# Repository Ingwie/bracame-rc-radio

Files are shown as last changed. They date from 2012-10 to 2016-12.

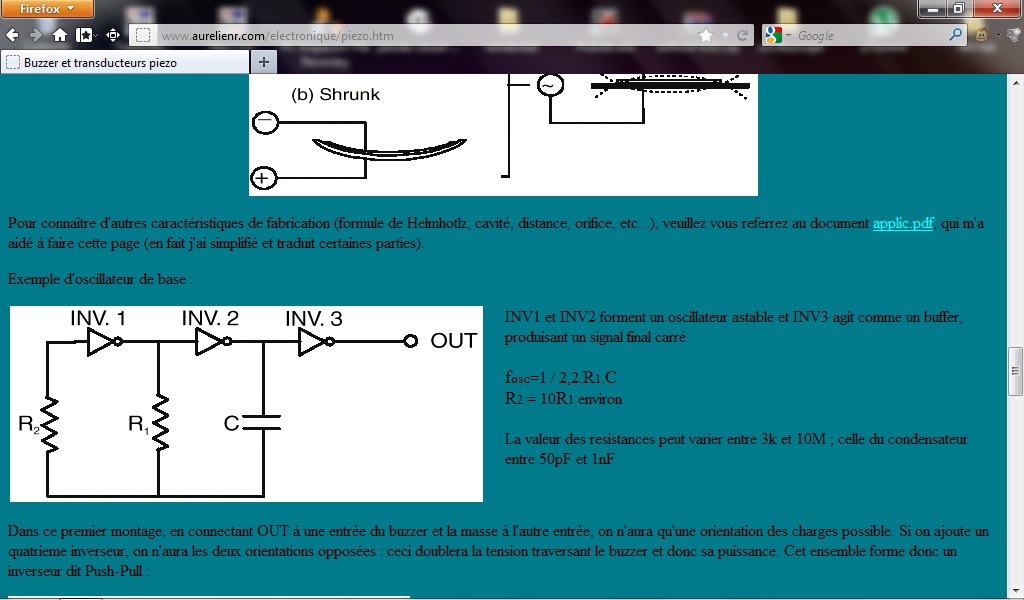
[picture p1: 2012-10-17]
wiki/oscilbuzzer.jpg

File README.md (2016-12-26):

# bracame-rc-radio
Automatically exported from code.google.com/p/bracame-rc-radio

Une radio RC pour avions maison à base de µ contrôleur STM8S. DIY RC TX.

Afficheur 2 X 16.

Émetteur au choix (compatible PPM)

8 voies en entrées et sorties :

8 sorties PPM (j'utilise le module DIY corona ...)

8 entrées : 6 proportionnelles : 2 manches + 2 potards (voir photo) 2 switchs 3 positions.

Expo, dualrate, min neutre max sur chaque voies. Consommation batterie moteur (simulée) 18 mixeurs : entrée, sortie, gain +, gain - et 5 courbes de 6 points par cadrant.

Et plein d'autres choses ..... 

Après plusieurs années de bons et loyaux services, abandon au profit d'openAVRc

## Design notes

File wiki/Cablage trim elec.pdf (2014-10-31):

Utilisation | Pin | LQFP pin# | Partagé Avec | Discovery/ pin#
| PA0 | N/A | N/A | N/A | 1 | 2 | 3 | 4 | 5 | 6 | 7 | 8 | 9
Quartz | PA1 | 2 | OscIn | CN1-2 | + | - | ppm+ | ppm- | trimdyn | tor1+ | tor1- | tor2+ | tor2-
Quartz | PA2 | 3 | OscOut | CN1-3
Entrée TOR1+ | PA3 | 9 | TIM3_CH1 / TIM2_CH3 | CN1-9
Entrée TOR1- | PA4 | 10 | Exclusive | CN1-10
Entrée TOR2+ | PA5 | 11 | Exclusive | CN1-11
Entrée TOR2- | PA6 | 12 | Exclusive | CN1-12
| PA7 | N/A | N/A | N/A
Entrée manche 1 | PB0 | 22 | TIM1_CH1N / AIN0 | CN3-10
Entrée manche 2 | PB1 | 21 | TIM1_CH2N / AIN1 | CN3-9
Entrée manche 3 | PB2 | 20 | TIM1_CH3N / AIN2 | CN3-8
Entrée manche 4 | PB3 | 19 | TIM1_ETR / AIN3 | CN3-7
Entrée potar 1 | PB4 | 18 | I2C_SCL / AIN4 | CN3-6
Entrée potar 2 | PB5 | 17 | I2C_SDA / AIN5 | CN3-5
Mesure batterie | PB6 | 16 | AIN6 | CN3-4
Phase | PB7 | 15 | AIN7 | CN3-3
| PC0 | N/A | N/A | N/A
Touche BAS | PC1 | 26 | TIM1_CH1 / UART2_CK | CN2-2
LCD Register Select | PC2 | 27 | TIM1_CH2 | CN2-3
LCD Enable | PC3 | 28 | TIM1_CH3 | CN2-4
LCD Bus 1 | PC4 | 29 | TIM1_CH4 | CN2-5
LCD Bus 2 | PC5 | 30 | SPI_SCK | CN2-6
LCD Bus 3 | PC6 | 33 | SPI_MOSI | CN3-9
LCD Bus 4 | PC7 | 34 | SPI_MISO | CN3-10
Sortie Led discovery/trim + | PD0 | 41 TIM3_CH2 / TIM1_BKIN / CLK_CCO | | CN4-5
SWIM | PD1 | 42 | SWIM | CN4-6
Sortie Trim - | PD2 | 43 | TIM3_CH1 / TIM2_CH3 | CN4-7
Sortie PPM | PD3 | 44 | TIM2_CH2 / ADC_ETR | CN4-8
Bip (buzzer) | PD4 | 45 | TIM2_CH1 / BEEP | CN4-9
Entrée Trim manche 1 | PD5 | 46 | UART2_TX | CN4-10
Entrée Trim manche 0 | PD6 | 47 | UART2_RX | CN4-11
Entrée Trim Dynamique | PD7 | 48 | TLI / TIM1_CH4 | CN4-12
Sécu Mot. | PE0 | 40 | CLK_CCO | CN4-4
I2C SCL (24C256) | PE1 | 39 | I2C_SCL | CN4-3
I2C SDA (24C256) | PE2 | 38 | I2C_SDA | CN4-2
Expo + DualRate | PE3 | 37 | TIM1_BKIN | CN4-1
| PE4 | N/A | N/A | N/A
Touche Droite | PE5 | 25 | SPI_NSS | CN2-1
Entrée Trim manche 3 | PE6 | 24 | AIN9 | CN3-12
Entrée Trim manche 2 | PE7 | 23 | AIN8 | CN3-11
Touche Gauche | PG0 | 35 | Exclusive | CN2-11
Touche Haut | PG1 | 36 | Exclusive | CN2-12

DB9

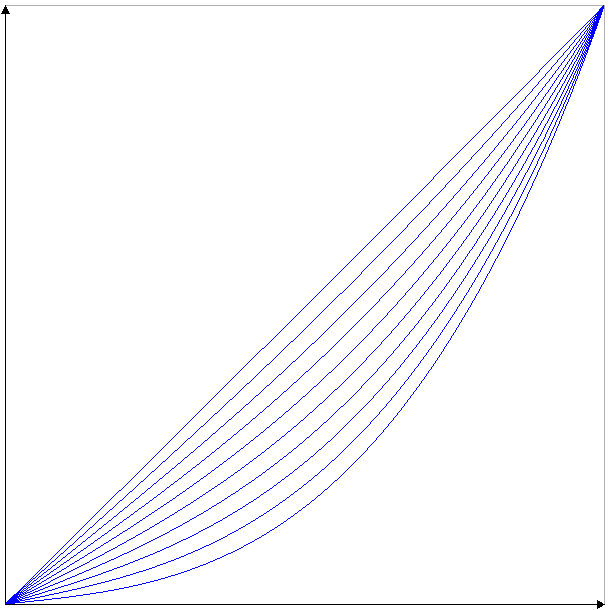
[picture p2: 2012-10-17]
wiki/expo.png

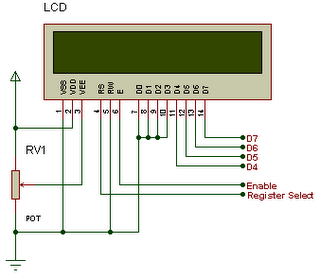
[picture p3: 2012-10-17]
wiki/lcd.png

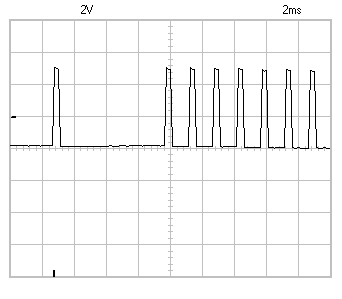
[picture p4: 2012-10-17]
wiki/ppm.bmp

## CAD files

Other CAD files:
branches/tx/src/rc-tx.stp

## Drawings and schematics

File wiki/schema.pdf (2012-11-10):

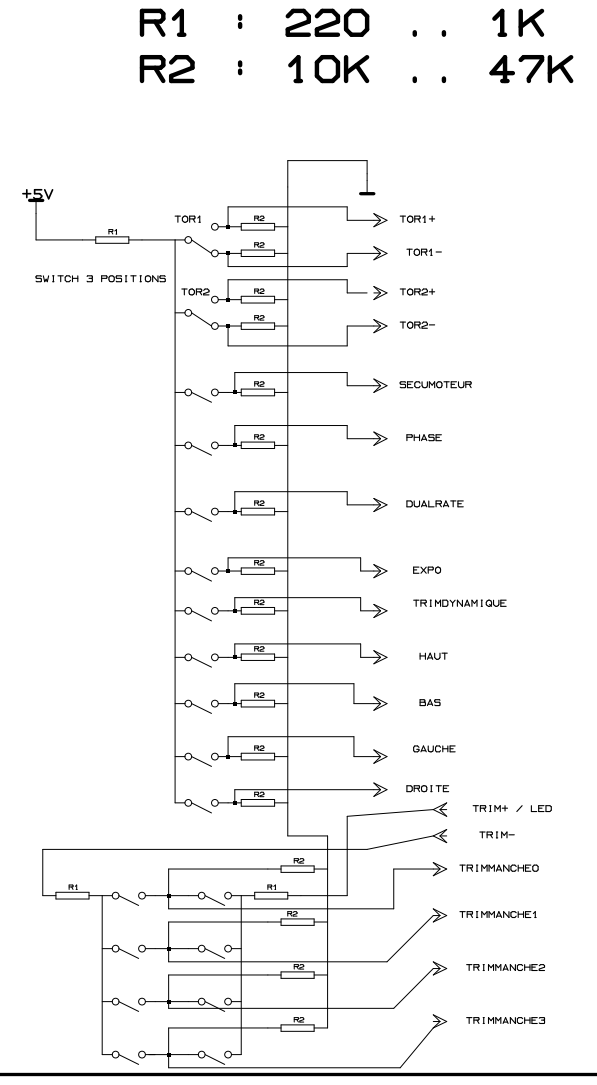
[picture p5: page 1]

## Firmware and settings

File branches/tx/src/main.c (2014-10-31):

/* Bracame RC TX */
/* */
/* Ajout de trims electroniques pour fonctionnement avec nouveaux manches (hitec aurora 9)*/
/* */
/* Ajout dans utilitaire : visualisation des entrées sorties et potars */
/* */
/* Ajout de la gestion du retour au neutre pour trimdyn */
/* */
/* Un seul etalonnage des manches pour tous les modeles : 5 possibles maintenant (petite modif), ajout réglage tempo du menu*/
/* */
/* Multiplexage des switchs secumoteur, phase, expo et dr liberation des entrées i2c pour ise en place d'une 24C256*/
/* */
/* Ecriture de routines perso i2c : le stm8 rev Y est buggé sur l'i2c. 24C256 fonctionnelle*/
/* (15 modèles 3 phases et 18 mixeurs maintenant. Reste a ajouter un switch 3 positions pour les phases*/
/* */
/* Amelioration de secumoteur */
/* */
/* Switch 3 positions Phase en place, cable sur PB7 (reste donc une place avec secumoteur */
/* */
/* */


#include "stm8s.h"
#include "tx.h"
#include "delay.h"
#include "hd44780.h"
#include "menu.h"
#include "iic.h"

extern _Bool Menu_on;
extern _Bool sec;
extern _Bool Menu_actif;
extern _Bool popup;
extern _Bool Menu_raz;
extern _Bool synchro;
extern u8 Tempo_menu;
extern u8 jeton;
extern u8 channel;

u8 modele_actuel;
u8 phase_actuelle = 0;
u8 phase_a_charger = 0;
_Bool phase_change = 0;
_Bool phase_changemenu = 0;
u8 nom_modele[12] = "           \n";



_Bool trimdyn = 0; // Lié a PD7
_Bool switchdr = 0; // PE2
_Bool expon = 0; // PE3
_Bool secumot = 1; // PE0
_Bool tor1plus = 0; // PA3
_Bool tor1moins = 0; // PA4
_Bool tor2plus = 0; // PA5
_Bool tor2moins = 0; // PA6
_Bool gazazero = 0; // Detection manche des gaz au mini pour fonction secumoteur

struct_input NEAR input;
struct_output NEAR output;
struct_param_phase NEAR param_phase[NUM_PHASE];
u16 trimmem[NUM_OUTPUT];


volatile _Bool flashencour = 0;
_Bool menudyn = 0;
_Bool switchinfo = 0;
_Bool haut = 0; // PG1
_Bool bas = 0; // PC1
_Bool gauche = 0; // PG0
_Bool droite = 0; // PE5

_Bool trim0plus = 0;
_Bool trim0moins = 0;
_Bool trim1plus = 0;
_Bool trim1moins = 0;
_Bool trim2plus = 0;
_Bool trim2moins = 0;
_Bool trim3plus = 0;
_Bool trim3moins = 0;
_Bool trimflag = 0;
_Bool trimchange = 0;
u8 trimstep = 2;

u16 temps_calcul_trame;
u8 secondesurcinq;
u8 secondes;
u8 minutes;
u16 chargeeaccus = 9999;

u8 ratiotrimdyn = 1;
u8 tempotrimdyn = 0;
u8 temptrimdyn = 20;
u8 tempsmenu = 10;
_Bool trimdynencour = 0;
_Bool manche0neutre = 0;
_Bool manche1neutre = 0;
_Bool manche2neutre = 0;
_Bool manche3neutre = 0;
_Bool trimdynmanche0 = 0;
_Bool trimdynmanche1 = 0;
_Bool trimdynmanche2 = 0;
_Bool trimdynmanche3 = 0;

u8 tempsbip1 = 0;
u8 tempsbip2 = 0;
u8 tempsbip3 = 0;
u8 tempsbip4 = 0;
u8 tempsbip5 = 0;
_Bool bipon = 1;


/////////////////////////////////////////////////////////////////////////////

/*void duree(void) // pour debugger optimiser
{
		static u16 debut;
		static u16 fin;
		static u16 temps;
		debut =  TIM3_GetCounter();  


		// fonction a mesurer
		//lectureswitch();

		fin = TIM3_GetCounter();
		if (fin > debut)
		{
				temps =(fin - debut) * 32;
				LCD_printtruc(1,9,"%i\n",temps);
				LCD_printtruc(2,10,"%i\n",channel);
		}
}*/

void bip(u8 temps1,u8 temps2,u8 temps3,u8 temps4,u8 temps5) // temps x 0.2 sec
{
	if (bipon)
	{
		GPIO_WriteLow(GPIOD,GPIO_PIN_4);
		tempsbip1 = temps1 + 1;
		tempsbip2 = temps2 + tempsbip1;
		tempsbip3 = temps3 + tempsbip2;
		tempsbip4 = temps4 + tempsbip3;
		tempsbip5 = temps5 + tempsbip4;
	}
}

void lcd_charge_spcaracteres(void)
{
	const char cur[64] =
	{
		0x00, 0x00, 0x00, 0x00, 0x00, 0x00, 0x00, 0x1F,
		0x00, 0x00, 0x00, 0x00, 0x00, 0x00, 0x1F, 0x00,
		0x00, 0x00, 0x00, 0x00, 0x00, 0x1F, 0x00, 0x00,
		0x00, 0x00, 0x00, 0x00, 0x1F, 0x00, 0x00, 0x00,
		0x00, 0x00, 0x00, 0x1F, 0x00, 0x00, 0x00, 0x00,
		0x00, 0x00, 0x1F, 0x00, 0x00, 0x00, 0x00, 0x00,
		0x00, 0x1F, 0x00, 0x00, 0x00, 0x00, 0x00, 0x00,
		0x1F, 0x00, 0x00, 0x00, 0x00, 0x00, 0x00, 0x00
	};
	
	LCD_CMD(CGRAM_address_start);
	LCD_LOAD_CGRAM(cur,8);
}

void biponoff(void)
{
	LCD_DISP_OFF();
	LCD_CLEAR_DISPLAY();
	Menu_actif = 1;
	popup = 1;
	Tempo_menu = 8;

	bipon = !bipon;
	switchinfo = 1;
	if (bipon)
	{
		LCD_printtruc(1,6,"Bip On",0);
		bip(2,1,1,0,0);
	}
	else
	{
		LCD_printtruc(1,6,"Bip Off",0);
	}
	
	LCD_DISP_ON();
}

void razchrono(void)
{
	minutes = secondes = 0;
	chargeeaccus = 9999;
	bip(2,1,2,0,0);
}

u8 nivbar(u16 sortie) // Pour baragraphe info
{	
	sortie -= (MIN_COURSE - MIN_COURSE/8);
	sortie /= 166;
	return sortie;
}

void info(void) // Affichage pendant le vol ...
{
	u8 i;
	u16 volt;
	u8 barout;
	char lhaut[NUM_OUTPUT + 1];
	char lbas[NUM_OUTPUT + 1];
	const char esp = 32;
	
	for(i = 0; i < NUM_OUTPUT ; i++)
	{
		barout = nivbar(output.usValueOut[i]); //calcul pour affichage pendant le vol
		
		switch (barout)
		{
		case 0:
			lbas[i] = '\0';
			lhaut[i] = esp;
			break;
		case 1:
			lbas[i] = '\1';
			lhaut[i] = esp;
			break;
		case 2:
			lbas[i] = '\2';
			lhaut[i] = esp;
			break;
		case 3:
			lbas[i] = '\3';
			lhaut[i] = esp;
			break;
		case 4:
			lbas[i] = '\4';
			lhaut[i] = esp;
			break;
		case 5:
			lbas[i] = '\5';
			lhaut[i] = esp;
			break;
		case 6:
			lbas[i] = '\6';
			lhaut[i] = esp;
			break;
		case 7:
			lbas[i] = '\7';
			lhaut[i] = esp;
			break;
		case 8:
			lbas[i] = esp;
			lhaut[i] = '\0';
			break;
		case 9:
			lbas[i] = esp;
			lhaut[i] = '\1';
			break;
		case 10:
			lbas[i] = esp;
			lhaut[i] = '\2';
			break;
		case 11:
			lbas[i] = esp;
			lhaut[i] = '\3';
			break;
		case 12:
			lbas[i] = esp;
			lhaut[i] = '\4';
			break;
		case 13:
			lbas[i] = esp;
			lhaut[i] = '\5';
			break;
		case 14:
			lbas[i] = esp;
			lhaut[i] = '\6';
			break;
		case 15:
			lbas[i] = esp;
			lhaut[i] = '\7';
			break;
		}
	}
	
	lhaut[NUM_OUTPUT] = 10; // Caractere "/n"
	lbas[NUM_OUTPUT] = 10;
	LCD_LOCATE(1,1);
	LCD_printstring(lhaut);
	LCD_LOCATE(2,1);
	LCD_printstring(lbas);

	// Canal en cours d'emission
	LCD_printtruc(1,9,"%u\n",channel);

	// Temps restant aprés la boucle de calcul de la trame
	temps_calcul_trame = (LONGUEUR_TRAME - temps_calcul_trame);
	temps_calcul_trame /= 1000;
	barout = (u8)(temps_calcul_trame);
	// 1 = 0.5 mS
	if (barout < 1) barout = '!';
	else if (barout < 3) barout = '?';
	else barout = '*';
	LCD_LOCATE(1,10);
	LCD_printchar(barout);
	
	// Horloge
	LCD_printtruc(1,12,"%2.2u\n",minutes);
	LCD_printtruc(1,14,":%2.2u\n",secondes);

	// Batterie
	volt = ADC1_GetBufferValue(6); //3.42 (697) 2.2 (452) ->  200.81 / VOLT + 0.05V *2 + diode
	volt += 68;
	LCD_printtruc(2,12,"%i\n",volt/100);
	LCD_printtruc(2,13,".%2.2iV\n",volt%100);
	if (volt < 750)
	{
		if (secondes == 0)
		{
			bipon = 1;
			bip(0,1,1,1,1);
			LCD_DISP_OFF();
			LCD_CLEAR_DISPLAY();
			LCD_printtruc(1,5,"BATTERIE\n",0);
			LCD_printtruc(2,6,"FAIBLE\n",0);
			LCD_DISP_ON();
		}
	}
}

void chronobat(void) // Autonomie batterie f des gaz
{
	u16 temp; static _Bool c = 0; static _Bool q = 0; static _Bool t = 0;
	static _Bool d = 0;

	if (param_phase[phase_actuelle].secumoteur != 255)
	{
		temp = output.usValueOut[param_phase[phase_actuelle].secumoteur];
		temp -= MIN_COURSE;
		temp /= 20;
		temp *= param_phase[phase_actuelle].ratiobat;
		if (temp == 0) temp = 1;
		temp /= 180;
		chargeeaccus -= temp;
		if (chargeeaccus > 9999) chargeeaccus = 0;
		temp = chargeeaccus/100;
		if (Menu_actif == 0)	LCD_printtruc(2,9,"%2.2u%%\n",temp);
		if((temp == 50) && (c == 0)) {bip(3,0,3,0,0); c = 1;}
		if ((temp == 40) && (q == 0)) {bip(6,0,6,0,0); q = 1;}
		if ((temp == 30) && (t == 0)) {bip(12,1,12,1,12); t = 1;}
		if ((temp == 20) && (d == 0)) {bip(12,2,36,1,36); d = 1;}
	}
}

s8 sortiepourcent(u16 sortie) // Valeurs des temps en %
{	
	s16 a;
	a= (sortie - NEUTRE_COURSE);
	a=a/10;
	return a;
}

u16 pourcentsortie(s8 pourcent) // % en temps
{ 
	return (u16)((pourcent * 10) + NEUTRE_COURSE);
}

void reset_modele(void)
{
	u8 i;
	u8 j;
	
	for(i = 0; i < 12; i++)
	{
		nom_modele[i] = 32;
	}
	//input
	for(i = 0; i < NUM_INPUT; i++)
	{
		param_phase[phase_actuelle].expo[i][0] = 0;
		param_phase[phase_actuelle].expo[i][1] = 0;
	}
	
	//mixer 
	for(i = 0; i < NUM_MIXER; i++)
	{
		param_phase[phase_actuelle].mixer[i].in = 255;
		param_phase[phase_actuelle].mixer[i].out = 255;
		param_phase[phase_actuelle].mixer[i].pente[0] = 0;
		param_phase[phase_actuelle].mixer[i].pente[1] = 0;
	}

	//output
	
	output.usValueOut[NUM_OUTPUT] =  LONGUEUR_TRAME; //22.5 ms
	
	for(i = 0; i < (NUM_INPUT + NUM_INPUT_SWITCH) ; i++)
	{
		param_phase[phase_actuelle].dr[i] = 100;
	}
	
	
	for(i = 0; i < NUM_OUTPUT ; i++)
	{
		output.usValueOut[i] = NEUTRE_COURSE;
		param_phase[phase_actuelle].usMinValue[i] = MIN_COURSE;
		param_phase[phase_actuelle].usNeutralValue[i] = NEUTRE_COURSE;
		param_phase[phase_actuelle].usMaxValue[i] = MAX_COURSE;
	}
	
	param_phase[phase_actuelle].secumoteur = 255;
	param_phase[phase_actuelle].ratiobat = 0;
	
	for(i = 0; i < NUM_COURBES; i++)
	{
		for(j = 0; j < NUM_POINTS_COURBE; j++)
		{
			param_phase[phase_actuelle].courbe[i][j] = 0;
		}
	}
}

void reset_neutre(void)
{
	u8 i;
	
	for(i = 0; i < NUM_OUTPUT ; i++)
	{
		param_phase[phase_actuelle].usNeutralValue[i] = NEUTRE_COURSE;
	}
	
}

void erreur_ee(u16 adresse) // Affiche un message en cas d'erreur avec la eeprom
{
	LCD_DISP_OFF();
	LCD_CLEAR_DISPLAY();
	Menu_actif = 1;
	popup = 1;
	Tempo_menu = 6;
	LCD_printtruc(1,4,"Erreur EE",0);
	LCD_printtruc(2,4,"adresse %i\n",adresse);
	LCD_DISP_ON();
	bip(3,0,0,0,0);
	Delayms(500);
}

void eeprom_ecrire(u16 adresse,u8* pdonnee,u8 taille) // Affiche un message en cas d'erreur d'ecriture eeprom
{
	if (!iic_ecrire(adresse,pdonnee,taille)) erreur_ee(adresse);
}

void eeprom_lire(u16 adresse,u8* pdat,u8 taille) // Affiche un message en cas d'erreur de lecture eeprom
{
	if (!iic_lire(adresse,pdat,taille)) erreur_ee(adresse);
}

void load_input(void) // taille : (6 x NUM_INPUT) (36) INPUT_LENGTH
{
	u8 i;
	u16 delta2;
	
	u16 addr = 20;
	
	flashencour = 1;
	
	for(i = 0; i < NUM_INPUT; i++)
	{	
		eeprom_lire(addr,(u8*)&input.channel[i].usMinValue,2);
		addr +=2;	
		
		eeprom_lire(addr,(u8*)&input.channel[i].usNeutralValue,2);
		addr +=2;	
		
		eeprom_lire(addr,(u8*)&input.channel[i].usMaxValue,2);
		addr +=2;	
		
		delta2 = (input.channel[i].usNeutralValue - input.channel[i].usMinValue);
		if (delta2 > 4) input.channel[i].pente[0] = 256000 / delta2;
		else input.channel[i].pente[0] = 65535;
		
		delta2 = (input.channel[i].usMaxValue - input.channel[i].usNeutralValue);
		if (delta2 > 4) input.channel[i].pente[1] = 256000 / delta2;
		else input.channel[i].pente[1] = 65535;
	}
	
	flashencour = 0;
}

void charge_nom_modele_ee(u8 modele)
{
	u16 addr = 64 + (NUM_PHASE * NUM_PAGE_PHASE * 64 * modele) ;
	
	eeprom_lire(addr,(u8*)&nom_modele,12);
	
	nom_modele[11] = '\n';
}

void charge_phase_ee(u8 phase) // Charge dans 3 pages de 64 octets
{
	u8 i;
	u8 j;
	u8 utemp;
	s8 stemp;
	u16 addr = 64 + (NUM_PHASE * NUM_PAGE_PHASE * 64 * modele_actuel) + ( NUM_PAGE_PHASE * 64 * phase);
	
	//nom du modele
	if (phase ==0) {eeprom_lire(addr,(u8*)&nom_modele,12);}
	addr+=12;
	nom_modele[11] = '\n';
	
	//secu moteur
	eeprom_lire(addr,(u8*)&utemp,1);
	param_phase[phase].secumoteur = utemp;
	addr++;
	// ratiobat
	eeprom_lire(addr,(u8*)&utemp,1);
	param_phase[phase].ratiobat = utemp;
	

	
	addr+=PLACE_1; //de la place pour autre chose ...
	
	//input
	for(i = 0; i < NUM_INPUT; i++)
	{
		//expo
		for(j = 0; j < 2;j++)
		{
			eeprom_lire(addr,(u8*)&stemp,1);
			param_phase[phase].expo[i][j] = stemp;
			addr++;
		}
	}
	
	//mixer
	for(i = 0; i < NUM_MIXER; i++)
	{
		eeprom_lire(addr,(u8*)&utemp,1);
		param_phase[phase].mixer[i].in = utemp;
		addr++;
		eeprom_lire(addr,(u8*)&utemp,1);
		if (param_phase[phase].mixer[i].in <= (NUM_INPUT + NUM_INPUT_SWITCH))
		param_phase[phase].mixer[i].out = utemp;
		else param_phase[phase].mixer[i].out = 255;
		addr++;
		eeprom_lire(addr,(u8*)&stemp,1);
		param_phase[phase].mixer[i].pente[0] = stemp;
		addr++;
		eeprom_lire(addr,(u8*)&stemp,1);
		param_phase[phase].mixer[i].pente[1] = stemp;
		addr++;
	}
	
	addr+=PLACE_2; //encore de la place !
	
	//output
	
	for(i = 0; i < (NUM_INPUT + NUM_INPUT_SWITCH) ; i++)
	{
		eeprom_lire(addr,(u8*)&utemp,1);		
		param_phase[phase].dr[i] = utemp;
		addr++;
	}

	
	for(i = 0; i < NUM_OUTPUT; i++) // Min et Max
	{
		eeprom_lire(addr,(u8*)&stemp,1);
		param_phase[phase].usMinValue[i] = pourcentsortie(stemp);
		addr++;
		eeprom_lire(addr,(u8*)&stemp,1);
		param_phase[phase].usMaxValue[i] = pourcentsortie(stemp);
		addr++;
	}
	for(i = 0; i < NUM_OUTPUT; i++) // Les neutres
	{
		eeprom_lire(addr,(u8*)&stemp,1);
		param_phase[phase].usNeutralValue[i] = pourcentsortie(stemp);
		addr++;
	}
	addr+=PLACE_3; //encore de la place !
	
	for(i = 0; i < NUM_COURBES; i++)
	{
		for(j = 0; j < NUM_POINTS_COURBE; j++)
		{
			eeprom_lire(addr,(u8*)&stemp,1);
			param_phase[phase].courbe[i][j] = stemp;
			addr++;
		}
	}

}

void charge_param_phase(void)
{
	u8 i;
	secumot = 1;
	for(i = 0; i < NUM_PHASE; i++)
	{
		charge_phase_ee(i);
	}
}

void sauve_numero_modele_actuel_ee(u8 num) // Memorise le modele chargé
{
	eeprom_ecrire(0,(u8*)&num,1);
}

void save_phase_ee(u8 modele,u8 phase) // Sauve dans 3 pages de 64 octets
{
	u8 i = 0;
	u8 j = 0;
	u8 utemp;
	s8 stemp;
	u16 addr = 64 + (NUM_PHASE * NUM_PAGE_PHASE * 64 * modele) + ( NUM_PAGE_PHASE * 64 * phase);
	
	//nom du modele
	nom_modele[11] = '\n';
	if (phase == 0) eeprom_ecrire(addr,(u8*)&nom_modele,12);
	addr+=12;
	
	//secu moteur
	utemp = param_phase[phase_actuelle].secumoteur;
	eeprom_ecrire(addr,(u8*)&utemp,1);
	addr++;
	utemp = param_phase[phase_actuelle].ratiobat;
	eeprom_ecrire(addr,(u8*)&utemp,1);

	
	addr+=PLACE_1; //de la place pour autre chose ...
	
	//input 
	for(i = 0; i < NUM_INPUT; i++)
	{
		//expo
		for(j = 0; j < 2;j++)
		{
			stemp = param_phase[phase_actuelle].expo[i][j];
			eeprom_ecrire(addr,(u8*)&stemp,1);
			addr ++;
		}
	}
	

	//mixer 
	for(i = 0; i < NUM_MIXER; i++)
	{
		utemp = param_phase[phase_actuelle].mixer[i].in;
		eeprom_ecrire(addr,(u8*)&utemp,1);
		addr++;
		utemp = param_phase[phase_actuelle].mixer[i].out;
		eeprom_ecrire(addr,(u8*)&utemp,1);
		addr++;
		stemp = param_phase[phase_actuelle].mixer[i].pente[0];
		eeprom_ecrire(addr,(u8*)&stemp,1);
		addr++;
		stemp = param_phase[phase_actuelle].mixer[i].pente[1];
		eeprom_ecrire(addr,(u8*)&stemp,1);
		addr++;
	}
	
	addr+=PLACE_2; //encore de la place !
	
	//output
	
	for(i = 0; i < (NUM_INPUT + NUM_INPUT_SWITCH) ; i++)
	{
		utemp = param_phase[phase_actuelle].dr[i];
		eeprom_ecrire(addr,(u8*)&utemp,1);		
		addr++;
	}

	
	for(i = 0; i < NUM_OUTPUT; i++) //Min et Max
	{		
		stemp = sortiepourcent(param_phase[phase_actuelle].usMinValue[i]);
		eeprom_ecrire(addr,(u8*)&stemp,1);
		addr ++;
		stemp = sortiepourcent(param_phase[phase_actuelle].usMaxValue[i]);
		eeprom_ecrire(addr,(u8*)&stemp,1);
		addr ++;
	}
	for(i = 0; i < NUM_OUTPUT; i++) // Les neutres ensemble
	{
		stemp = sortiepourcent(param_phase[phase_actuelle].usNeutralValue[i]);
		eeprom_ecrire(addr,(u8*)&stemp,1);
		addr ++;
	}
	
	addr+=PLACE_3; //encore de la place ! // 216
	
	for(i = 0; i < NUM_COURBES; i++)
	{
		for(j = 0; j < NUM_POINTS_COURBE; j++)
		{
			stemp = param_phase[phase_actuelle].courbe[i][j];
			eeprom_ecrire(addr,(u8*)&stemp,1);
			addr ++;
		}
	}
}

void save_neutre_ee(void) // Sauve les neutre
{
	u8 i;
	s8 stemp[NUM_OUTPUT];
	u16 addr = 64 + (NUM_PHASE * NUM_PAGE_PHASE * 64 * modele_actuel) + ( NUM_PAGE_PHASE * 64 * phase_actuelle);
	addr += 144;
	
	flashencour = 1;
	
	for(i = 0; i < NUM_OUTPUT; i++)
	{
		stemp[i] = sortiepourcent(param_phase[phase_actuelle].usNeutralValue[i]);
	}
	eeprom_ecrire(addr,(u8*)&stemp,NUM_OUTPUT);
	
	flashencour = 0;
}

void changeratiotrimdyn(void) // Divise les courses lors du trimdyn
{
	if (ratiotrimdyn < 4) ratiotrimdyn++;
	else ratiotrimdyn = 1;

	LCD_DISP_OFF();
	LCD_CLEAR_DISPLAY();
	Menu_actif = 1;
	popup = 1;
	Tempo_menu = 8;
	switchinfo = 1;

	LCD_printtruc(1,2,"Ratio trimdyn",0);
	LCD_printtruc(2,6," ~ %u\n",ratiotrimdyn);
	LCD_DISP_ON();
	
	bip(1,1,0,1,0);

}

void settrimdyn(void) // Applique les trims dynamiques
{
	u8 i;

	for(i = 0; i < NUM_MIXER ; i++)
	{
		u8 in = param_phase[phase_actuelle].mixer[i].in;
		u8 out = param_phase[phase_actuelle].mixer[i].out;
		
		if ((out < NUM_OUTPUT) && (in < 4)) // trim dynamique que sur les sorties pilotées par les manches
		{
			if (out != param_phase[phase_actuelle].secumoteur) param_phase[phase_actuelle].usNeutralValue[out] = trimmem[out]; // et pas la voie moteur
		}
	}
	trimdynencour = trimdynmanche0 = trimdynmanche1 = trimdynmanche2 = trimdynmanche3 = 1; // recherches des neutres
	trimdyn = 0;
	trimchange = 1; // Sauvegarde des nouveaux neutres
}

void memtrimdyn(void) // Active la memorisation des valeurs des sorties si appuis sur bouton trimdyn (dans compute_mixer)
{
	trimdyn = 1;
	tempotrimdyn = temptrimdyn; // Charge la tempo
	bip(2,0,0,0,0);
}
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
void main(void)
{
	initialise();
	enableInterrupts();
	TIM3_Cmd(ENABLE); // 0.2 seconde
	TIM4_Cmd(ENABLE); // 0.001 seconde
	
	/* LCD chargement table de caracteres*/
	LCD_INIT();
	lcd_charge_spcaracteres();


	eeprom_lire(0,(u8*)&modele_actuel,1); // Dernier modele chargé
	load_input();
	charge_param_phase();
	
	// Lecture des switchs multiplexes
	GPIO_WriteLow(GPIOD, GPIO_PIN_0); // led on trim+ off
	GPIO_WriteHigh(GPIOD, GPIO_PIN_2); // trim- on
	lectureswitchmultiplex();
	Delayms(1);
	lectureswitchmultiplex();
	phase_change = 0;
	phase_actuelle = phase_a_charger;
	lectureswitch();
	
	
	LCD_CLEAR_DISPLAY();
	LCD_LOCATE(1,1);
	LCD_printstring(nom_modele);
	LCD_printtruc(1,13,"%2.2u.\n",modele_actuel+1);
	LCD_printtruc(1,16,"%u\n",phase_actuelle);
	LCD_printtruc(2,4,"Chargement\n",0);

	Delayms(1000);
	LCD_CLEAR_DISPLAY();
	
	synchro = 0;
	channel = 0;
	calcultrame();
	TIM2_SetAutoreload(output.usValueOut[0]);
	TIM2_Cmd(ENABLE);	
	

	while (1)
	{

		if (channel != 256)
		{	

			// menu
			if (Menu_on)	
			{
				//BAS
				bas = GPIO_ReadInputPin(GPIOC,GPIO_PIN_1);
				//DROITE
				droite = GPIO_ReadInputPin(GPIOE,GPIO_PIN_5);
				//GAUCHE
				gauche = GPIO_ReadInputPin(GPIOG,GPIO_PIN_0);
				//HAUT
				haut = GPIO_ReadInputPin(GPIOG,GPIO_PIN_1);
				
				
				Menu_on = 0;
				
				if ((((bas || gauche || droite || menudyn) || phase_changemenu) && Menu_actif && !popup) || haut)
				{				
					if (menudyn) menudyn = 0;
					Menu_actif = Menu_raz = 1;
					Menu();
					switchinfo = 1;
					phase_changemenu = 0;
				}	
			}

			if (channel == 0)
			{
				if (trimchange)
				{
					save_neutre_ee();
					trimchange = 0;
				}
				// baragraphe, etc
				if ((sec) && (!Menu_actif))	
				{
					chronobat();
					if (switchinfo)
					{
						switchinfo = 0;
						LCD_CLEAR_DISPLAY();
					}
					info();
					sec = 0;
					if (bas) changeratiotrimdyn();
					if (gauche) razchrono();
					if (droite) biponoff();
				}
			}
		}
	}
}

#ifdef USE_FULL_ASSERT

/**
* @brief  Reports the name of the source file and the source line number
* where the assert_param error has occurred.
* @param file: pointer to the source file name
* @param line: assert_param error line source number
* @retval 
* None
*/
void assert_failed(u8* file, u32 line)
{ 
	/* User can add his own implementation to report the file name and line number,
	ex: printf("Wrong parameters value: file %s on line %d\r\n", file, line) */
	LCD_printtruc(1,1,"file %s \n",file);
	LCD_printtruc(1,1,"line %d\r\n",line);

	/* Infinite loop */
	while (1)
	{

	}
}
#endif



/******************* fin *****END OF FILE****/

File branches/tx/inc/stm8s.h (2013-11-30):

/**
******************************************************************************
* @file    stm8s.h
* @author  MCD Application Team
* @version V2.1.0
* @date    18-November-2011
* @brief   This file contains all HW registers definitions and memory mapping.
******************************************************************************
* @attention
*
* THE PRESENT FIRMWARE WHICH IS FOR GUIDANCE ONLY AIMS AT PROVIDING CUSTOMERS
* WITH CODING INFORMATION REGARDING THEIR PRODUCTS IN ORDER FOR THEM TO SAVE
* TIME. AS A RESULT, STMICROELECTRONICS SHALL NOT BE HELD LIABLE FOR ANY
* DIRECT, INDIRECT OR CONSEQUENTIAL DAMAGES WITH RESPECT TO ANY CLAIMS ARISING
* FROM THE CONTENT OF SUCH FIRMWARE AND/OR THE USE MADE BY CUSTOMERS OF THE
* CODING INFORMATION CONTAINED HEREIN IN CONNECTION WITH THEIR PRODUCTS.
*
* <h2><center>&copy; COPYRIGHT 2011 STMicroelectronics</center></h2>
******************************************************************************
*/

/* Define to prevent recursive inclusion -------------------------------------*/
#ifndef __STM8S_H
#define __STM8S_H

/** @addtogroup STM8S_StdPeriph_Driver
* @{
*/

/* Uncomment the line below according to the target STM8S or STM8A device used in your
application. */

/* #define STM8S208 */      /*!< STM8S High density devices with CAN */
/* #define STM8S207 */      /*!< STM8S High density devices without CAN */
/* #define STM8S007 */      /*!< STM8S Value Line High density devices */
/* #define STM8AF52Ax */    /*!< STM8A High density devices with CAN */
/* #define STM8AF62Ax */    /*!< STM8A High density devices without CAN */
#define STM8S105 */      /*!< STM8S Medium density devices */
/* #define STM8S005 */      /*!< STM8S Value Line Medium density devices */
/* #define STM8AF626x */    /*!< STM8A Medium density devices */
/* #define STM8S103 */      /*!< STM8S Low density devices */
/* #define STM8S003 */      /*!< STM8S Value Line Low density devices */
/* #define STM8S903 */      /*!< STM8S Low density devices */

/*   Tip: To avoid modifying this file each time you need to switch between these
		devices, you can define the device in your toolchain compiler preprocessor. 

- High-Density STM8A devices are the STM8AF52xx STM8AF6269/8x/Ax,
	STM8AF51xx, and STM8AF6169/7x/8x/9x/Ax microcontrollers where the Flash memory
	density ranges between 32 to 128 Kbytes
- Medium-Density STM8A devices are the STM8AF622x/4x, STM8AF6266/68,
	STM8AF612x/4x, and STM8AF6166/68 microcontrollers where the Flash memory 
	density ranges between 8 to 32 Kbytes
- High-Density STM8S devices are the STM8S207xx, STM8S007 and STM8S208xx microcontrollers
	where the Flash memory density ranges between 32 to 128 Kbytes.
- Medium-Density STM8S devices are the STM8S105x and STM8S005 microcontrollers
	where the Flash memory density ranges between 16 to 32-Kbytes.
- Low-Density STM8S devices are the STM8S103xx, STM8S003 and STM8S903xx microcontrollers
	where the Flash density is 8 Kbytes. */

#if !defined (STM8S208) && !defined (STM8S207) && !defined (STM8S105) && \
	!defined (STM8S103) && !defined (STM8S903) && !defined (STM8AF52Ax) && \
	!defined (STM8AF62Ax) && !defined (STM8AF626x) && !defined (STM8S007) && \
	!defined (STM8S003)&& !defined (STM8S005) 
#error "Please select first the target STM8S/A device used in your application (in stm8s.h file)"
#endif

/******************************************************************************/
/*                   Library configuration section                            */
/******************************************************************************/
/* Check the used compiler */
#if defined(__CSMC__)
#define _COSMIC_
#elif defined(__RCST7__)
#define _RAISONANCE_
#elif defined(__ICCSTM8__)
#define _IAR_
#else
#error "Unsupported Compiler!"          /* Compiler defines not found */
#endif

#if !defined  USE_STDPERIPH_DRIVER
/* Comment the line below if you will not use the peripherals drivers.
In this case, these drivers will not be included and the application code will be
based on direct access to peripherals registers */
#define USE_STDPERIPH_DRIVER
#endif

/**
* @brief  In the following line adjust the value of External High Speed oscillator (HSE)
used in your application

Tip: To avoid modifying this file each time you need to use different HSE, you
		can define the HSE value in your toolchain compiler preprocessor.
*/
#if !defined  HSE_Value
#if defined (STM8S208) || defined (STM8S207) || defined (STM8S007) || defined (STM8AF52Ax) || \
	defined (STM8AF62Ax)
#define HSE_VALUE ((u32)24000000) /* Value of the External oscillator in Hz*/
#else
#define HSE_VALUE ((u32)16000000) /* Value of the External oscillator in Hz*/
#endif /* STM8S208 || STM8S207 || STM8S007 || STM8AF62Ax || STM8AF52Ax */
#endif /* HSE_Value */

/**
* @brief  Definition of Device on-chip RC oscillator frequencies
*/
#define HSI_VALUE   ((uint32_t)16000000) /*!< Typical Value of the HSI in Hz */
#define LSI_VALUE   ((uint32_t)128000)   /*!< Typical Value of the LSI in Hz */

#ifdef _COSMIC_
#define FAR  @far
#define NEAR @near
#define TINY @tiny
#define EEPROM @eeprom
#define CONST  const
#elif defined (_RAISONANCE_) /* __RCST7__ */
#define FAR  far
#define NEAR data
#define TINY page0
#define EEPROM eeprom
#define CONST  code
#if defined (STM8S208) || defined (STM8S207) || defined (STM8S007) || defined (STM8AF52Ax) || \
	defined (STM8AF62Ax)
/*!< Used with memory Models for code higher than 64K */
#define MEMCPY fmemcpy
#else /* STM8S903, STM8S103, STM8S003, STM8S105, STM8AF626x */
/*!< Used with memory Models for code less than 64K */
#define MEMCPY memcpy
#endif /* STM8S208 or STM8S207 or STM8S007 or STM8AF62Ax or STM8AF52Ax */ 
#else /*_IAR_*/
#define FAR  __far
#define NEAR __near
#define TINY __tiny
#define EEPROM __eeprom
#define CONST  const
#endif /* __CSMC__ */

/* For FLASH routines, select whether pointer will be declared as near (2 bytes,
to handle code smaller than 64KB) or far (3 bytes, to handle code larger 
than 64K) */

#if defined (STM8S105) || defined (STM8S005) || defined (STM8S103) || defined (STM8S003) || \
	defined (STM8S903) || defined (STM8AF626x)
/*!< Used with memory Models for code smaller than 64K */
#define PointerAttr NEAR
#else /* STM8S208 or STM8S207 or STM8AF62Ax or STM8AF52Ax */
/*!< Used with memory Models for code higher than 64K */
#define PointerAttr FAR
#endif /* STM8S105 or STM8S103 or STM8S003 or STM8S903 or STM8AF626x */

/* Uncomment the line below to enable the FLASH functions execution from RAM */
#if !defined (RAM_EXECUTION)
/* #define RAM_EXECUTION  (1) */
#endif /* RAM_EXECUTION */

#ifdef RAM_EXECUTION
#ifdef _COSMIC_
#define IN_RAM(a) a
#elif defined (_RAISONANCE_) /* __RCST7__ */
#define IN_RAM(a) a inram
#else /*_IAR_*/
#define IN_RAM(a) __ramfunc a
#endif /* _COSMIC_ */
#else 
#define IN_RAM(a) a
#endif /* RAM_EXECUTION */
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

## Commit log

2012-10-14 Amélioration de l'affichage des mixeurs Ajout réglage du diviseur du trimdyn Affichage des entrées sorties
2012-10-22 Ajout trim electroniques et visualisation de données brutes ( sorties, entrees, potars)
2012-10-31 Detection des neutres des manches pour le trimdynamique
2012-11-01 Ajout d'un bip pour l'affichage popup (trmdyn, bip) réaffectation des entrées trim elec.
2012-11-02 Enlevé kolossal bug ! (gestion des trims elec en tenant compte des mixeurs !!) Testé sur zackspeed : OK
    [main.c, menu.c]
2012-11-02 Elimination des interaction des potars lors des trimdyns avec mixages complexes
2012-11-10 Ajout schema de switchs, modification des plages de gain
2012-12-29 Un seul etalonnage des manches pour tous les modèles : 5 possibles maintenant (petite modif), ajout réglage tempo du menu
2013-01-30 Utilisation de TIM4 irq 23 pour la fonction Delayms. Moins de latence lors des delay
2013-02-03 Mise en ligne de tous les fichiers nécessaires. Les dualrates s'appliquent sur les entrées maintenant.
    [rc-tx.stp]
2013-03-11 Simplification du code, optimisation et réglage du bug des dualrates
    [main.c, menu.c]
2013-03-23 Réglé bug dans fonction sauveneutre.
    [main.c, menu.c]
2013-08-04 Amélioration des bips indiquant le niveau batterie restant. Le switch DR permet un incrément de 1 lors des réglages
2013-10-22 Multiplexage des switchs secumoteur, phase, expo et dr liberation des entrées i2c pour ise en place d'une 24C256
2013-11-03 Ajout menu nom du modele. les pin sda et scl sont en GPIO_MODE_OUT_OD_HIZ_FAST
2013-11-30 Ajout d'une eeprom 24C256 15 modèles 18 mixeurs (on peut faire beaucoup plus maintenant)
    [rc-tx.stp]
2013-12-01 Amélioration de secumoteur (Merci pour les doigts !)
2014-10-31 Switch 3 positions Phase en place, cable sur PB7 (reste donc une place avec secumoteur
2016-04-16 Annonce de l'arrêt du développement

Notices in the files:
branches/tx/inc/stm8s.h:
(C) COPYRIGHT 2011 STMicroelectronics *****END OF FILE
